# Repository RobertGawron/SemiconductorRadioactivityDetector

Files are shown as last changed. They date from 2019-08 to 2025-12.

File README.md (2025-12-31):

# Semiconductor Radioactivity Detector

## Summary

There are many ways to measure radioactivity levels. Semiconductor detectors sense interactions between ionizing radiation and a p-n junction. Since most hobbyists use Geiger-Muller-based detectors (which are lamp-based devices, not semiconductors), I think it's a cool idea to explore this semiconductor-based approach.

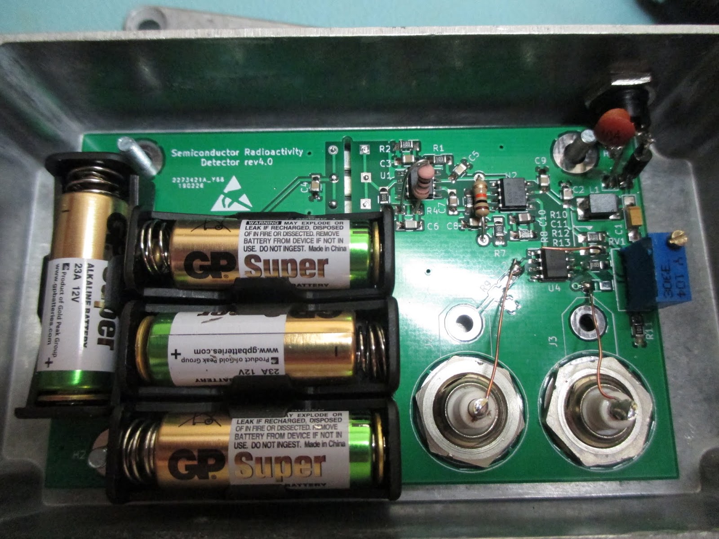
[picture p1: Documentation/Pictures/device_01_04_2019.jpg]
sensor viewed from the inside


## System Architecture

System Architecture of the Semiconductor Radioactivity Detector

## Additional sub-components used

### Hardware Data Logger

A pulse counter based on the STM32 and ESP chips that can send the measurements via WiFi for further processing, store them on an SD card, or display them to the user. This is an [open-source and open-hardware project that I created, available on GitHub.](https://github.com/RobertGawron/HardwareDataLogger)

### Auxiliary Board (Power Supply + Logic Level Converter)

An auxiliary board was developed later on to fix things that weren’t included on the original board (because it's easier to add a new board than to rework the whole device). This board isn’t really a successful one, but it does its job. It has:

**12V power supply (powered from a 15V wall adapter).** The device needs a very low-noise power supply. Originally, it was powered by a high-quality lab power supply. However, to make it more versatile, I tried using a cheap Chinese power supply and add a board with a power regulator. 

In the first revision, I chose the NCP1117 stabiliser, but it was too noisy. This caused the sensor's output to oscillate randomly, which made the device rather pointless. I made it work by adding plenty of capacitors on the input and output, though this was always a temporary solution. 

In the new version, I will be replacing it with the TPS7A2601DRVR.

**Logic level converter,** to convert logic levels from 12V (high) and 0V (low)—as output by the sensor—to 3.3V (high) and 0V (low), which is standard for STM32 and cheap Chinese logic analyzers. 

In the first version, I just used an open-collector configuration, but this made the device unable to work directly with cheap 3.3V logic analyzers, which need either 0V (low state) or 3.3V (high state).

In the new version, I added a cheap 3.3V stabiliser to provide the correct high state.

## Hardware

All hardware was done using KiCad.

The sensor assembly needs care, as this device is extremely sensitive; [more details are presented in this README.](./Hardware/SemiconductorRadioactivityDetector/README.md)

The sensor circuit is shown below.

Circuit of the Semiconductor Radioactivity Detector

The new design of the auxiliary board is shown below, integrated with the whole device. It's the small PCB on the right side of the image. The render was done using Blender.

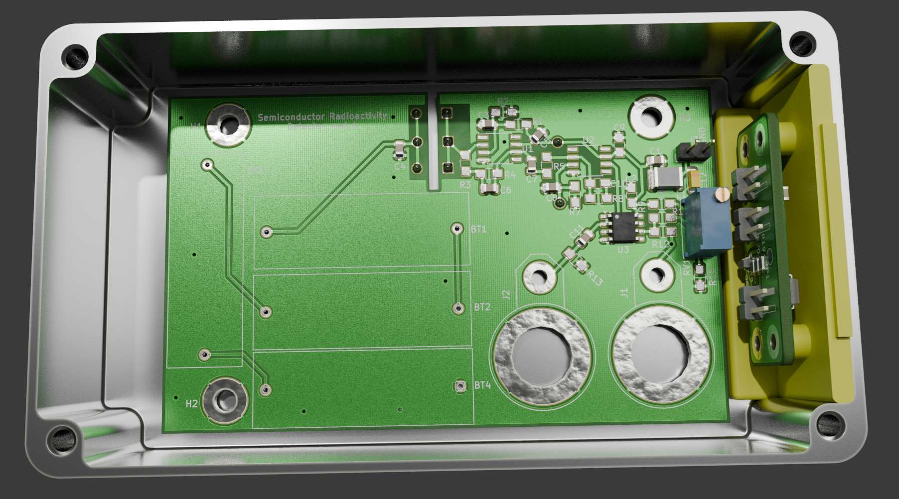
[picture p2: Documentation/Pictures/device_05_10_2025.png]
Auxiliary Board


Circuit of the Auxiliary Board is shown below.

Circuit of the Auxiliary Board

## Mechanic

Before ordering PCBs and the 3D print for the auxiliary holder, how could I be sure everything would fit? Instead of redoing things many times, I took the model of the old PCB, the new PCB that would be the addition to it, the 3D holder, and the metal enclosure (which is a popular consumer enclosure), placed them all accordingly in Blender, and checked if everything fit.

[The needed tools and the workflow are presented in this README.](./Mechanic/README.md)

## Software

[There are some Python and R scripts available](./Software/DataAcquisition/) for gathering data from the device. These were developed during the initial testing phase and may still be useful due to their simplicity.

In the future, the goal is to transition to using the [Hardware Data Logger](https://github.com/RobertGawron/HardwareDataLogger), which provides a more versatile and efficient way to collect measurements.

## Project History

 * [First Unsuccessful Attempts](https://robertgawron.blogspot.com/2016/12/semiconductor-radioactivity-detector.html)
semiconductor-radioactivity-detector.html) - the biggest issue was the lack of proper shielding. Due to the extremely high amplification levels, the device either failed to function or began oscillating uncontrollably without adequate shielding.
* [First Working Version](https://robertgawron.blogspot.com/2019/02/semiconductor-radioactivity-detector.html) - this was a simplified version of the current project. It lacked both polarization voltage and an ADC converter, but it laid the foundation for further improvements.

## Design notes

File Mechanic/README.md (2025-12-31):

# Purpose

Create a 3D-printed holder for the auxiliary board and visualize in Blender if it, the PCBs, and the chassis all fit together.

# Needed tools

* 1x https://www.tme.eu/Document/f0db5de1affb473276670eeca20421a8/hm-1550b.pdf
* 4x M2.5 nuts
* 4x Heat Set Insert Nuts M2.5 outside diameter 4mm
* 1x 3d printed model of the [PcbTray](./PcbTray/) - see more details below.

# Needed Software

* KiCad (for PCB design) + the pcb2blender extension
* OpenSCAD (for modeling the 3D-printed holder) + FreeCAD (for adding fillets and for file format conversion)
* Blender (to merge it all) + the pcb2blender extension

# Modeling Everything in Blender

It is to visualize how all the components fit together. This is only needed when changing the board's dimensions, hole placement, or the design of the PCB holder.

### Export the PCB from KiCad to Blender. 

Fortunately, there is a KiCad/Blender extension called pcb2blender that needs to be installed in both tools. The exported file needs to have the .pcb3d extension; otherwise, Blender fails to import it and the error message says nothing useful.

### Export STL models from FreeCAD to Blender

FreeCAD can export files to .STL, which Blender can then import. During the import in Blender, the scale of the .STL object needs to be set to 0.001. I don't know why.

### Export STEP models to Blender

The model of the metal enclosure for the device I found on the producer’s site, although it was in .STEP format, which Blender doesn't recognize. FreeCAD can import .STEP files and then export them to .STL, which works for Blender.

### Arrange models in Blender 

Now, when all the models are imported into Blender, it's time to arrange them in x, y, z and rotate them so they compose a real device. This could be done manually but would be very tedious; fortunately, Blender can be scripted in Python, and this way all objects can be correctly positioned. Just click the "Run" icon in Blender's scripting section. 

The script is in the project's repo too, it's just that it's not directly visible, but can be accessed via the "Scripting" tab in Blender once the Blender project is opened.

# Modeling the Auxiliary PCB Holder

It is to generate the file for 3D printing.

* The model is created in OpenSCAD.
* In FreeCAD, create a new project and click File > Open to select the OpenSCAD file.
* Add fillets to the model.
* Click File > Export and save it as an .stl file.

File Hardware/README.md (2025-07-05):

# Hardware

* [Semiconductor Radioactivity Detector](./SemiconductorRadioactivityDetector) - the main project for the sensor.
* [Power Supply + Logic Level Converter](./PowerSupply/) - auxiliary board to provide stable and low-noise power to the sensor, and to convert logic levels from 12V (high) and 0V (low) — as output by the sensor — to 3.3V (high) and 0V (low), which is standard for STM32 and cheap Chinese logic analyzers.

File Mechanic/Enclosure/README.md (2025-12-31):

# Specification

Datasheet of the Chassis:

https://www.tme.eu/Document/f0db5de1affb473276670eeca20421a8/hm-1550b.pdf

.STEP model:

https://www.hammfg.com/part/1550B?referer=electronics/small-case

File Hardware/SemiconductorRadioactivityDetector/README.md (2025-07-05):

# Extra Modifications

* The device needs to be completely shielded from sunlight and electromagnetic interference. It should be placed in a grounded metal case. Where the sensor is located, a hole should be drilled and covered with aluminum foil. This taped hole is necessary because the metal enclosure is too thick and would block too much of the radiation. The foil is needed because the signal from sunlight is much stronger, and it would overwhelm the sensor, effectively turning it into a light detector.
* As close as possible to the input power socket, I placed 1n/16V and 100n/16V capacitors in parallel. Without them, the device began oscillating randomly.
* A Schottky diode is connected in series after the extra capacitors mentioned above to reduce the risk of damaging the device when the power supply is connected incorrectly. I'm not sure if it will help enough, but I’ve already damaged one PCB this way, so now it's included.

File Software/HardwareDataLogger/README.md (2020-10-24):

# HardwareDataLogger

 

## Summary

It's a simple hardware data logger, that presents data both on LCD and via COM port so it's possible to gather data using PC and do further analysis. Currently it supports only pulse counting.

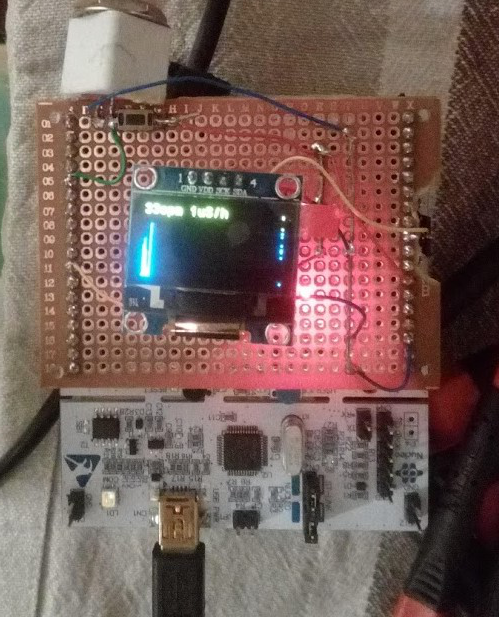
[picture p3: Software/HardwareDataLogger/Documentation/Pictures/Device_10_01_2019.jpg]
Device Picture


## Hardware

The device is based on NUCLEO-F091RC evaluation board with added custom-made shield.

TODO: hardware documentation of the shield.

## Software

Firmware were made using CubeMX, Eclipse is used for firmware development.

PC Simulation of Firmware was made using Python+Qt, it uses build .so variant of the firmware (Makefile is used for firmware variant generation).

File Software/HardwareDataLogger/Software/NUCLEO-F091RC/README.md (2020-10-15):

# Firmware for NUCLEO-F091RC board

The project has two build configurations:
* for generating binary, this is used for flashing, use Eclipse project
* for generating shared library, this is used for PC simulation, use Makefile

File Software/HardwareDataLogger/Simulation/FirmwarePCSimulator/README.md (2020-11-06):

# PC Simulator for firmware

This project consists of two parts:

- firmware that is built to sharable object (.so)
- python script that loads this sharable object, and acts as a mockup of hardware

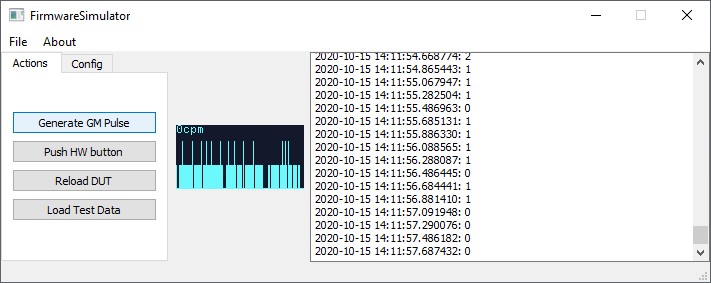
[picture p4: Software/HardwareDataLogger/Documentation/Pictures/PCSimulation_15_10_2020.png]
Simulator Picture


Note that in order to load .so object into an application, both of them needs to be 32bits, or 64bits. In case of errors during loading .so object, check your version on Python and gcc (both should be either 32bits or 64bits).

## Requirements
- Install PyQt5

```pip install PyQt5```
- Install gcc an makefile

## Usage
- Build firmware, in Software/NUCLEO-F091RC directory execute:

```make```

- Start the simulation, in Simulation/FirmwarePCSimulator execute:

```python main.py```

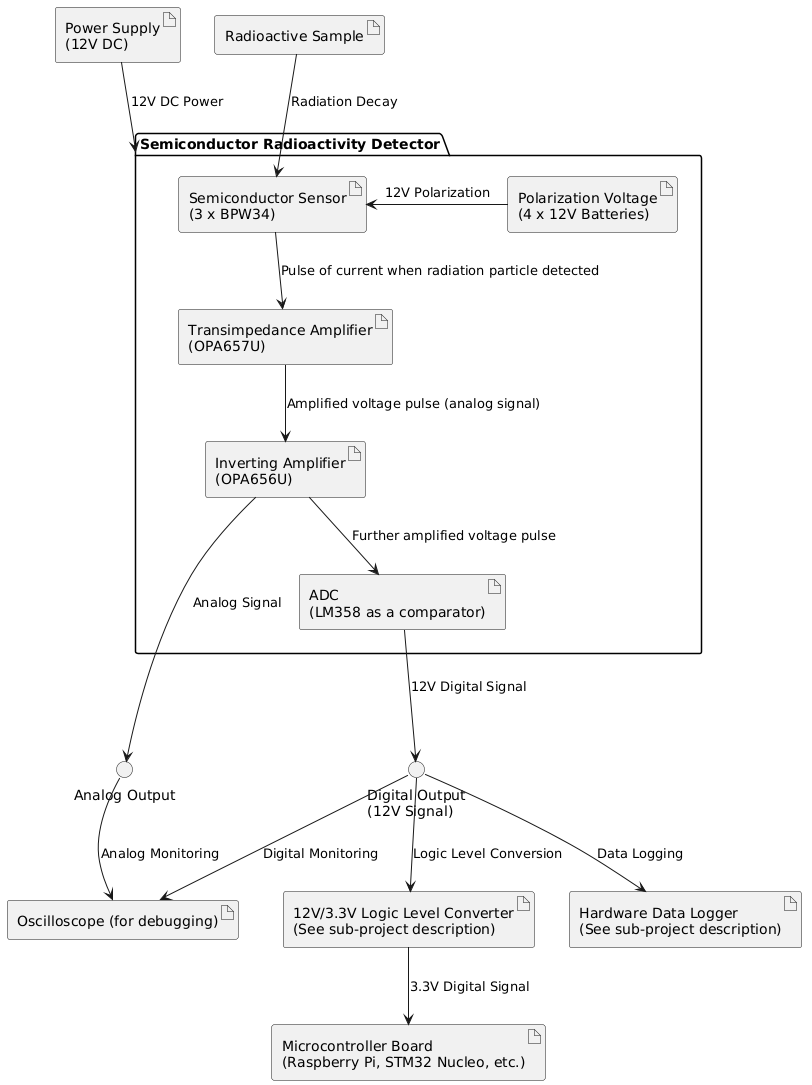
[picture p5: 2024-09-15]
Documentation/Diagrams/ArchitectureOverview-1.png

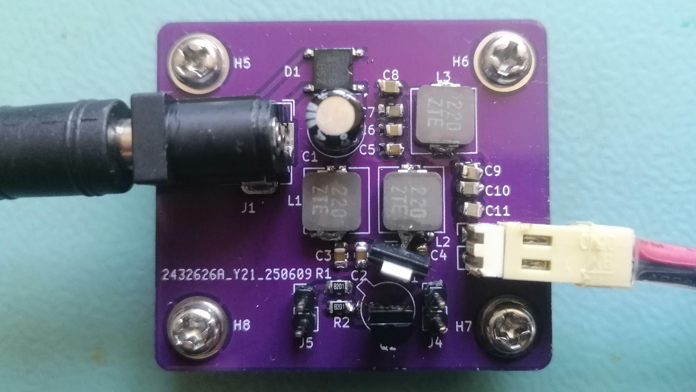
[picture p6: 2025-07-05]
Documentation/Pictures/auxiliary_board_05_07_2025.jpg

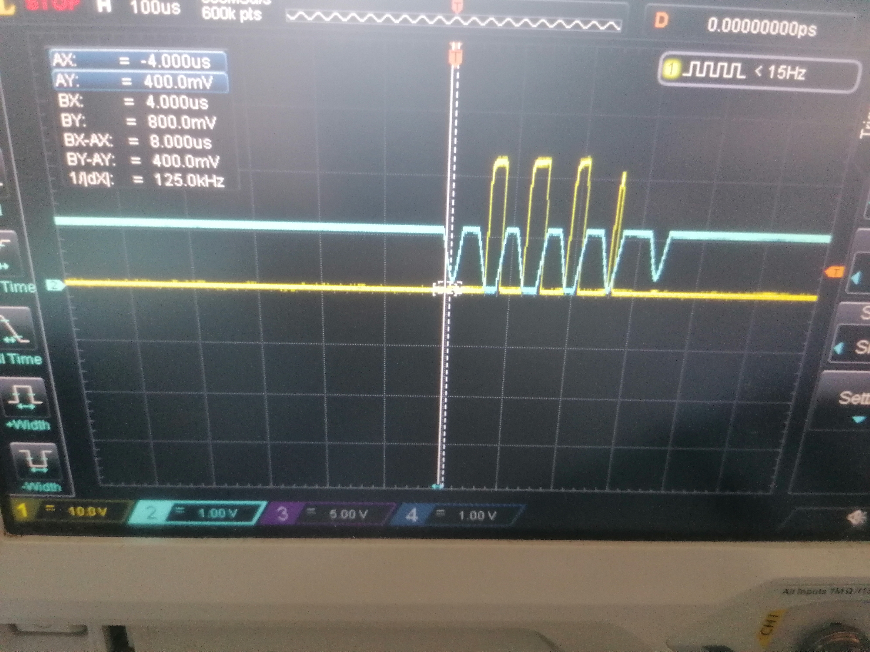
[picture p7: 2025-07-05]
Documentation/Pictures/distortion_05_07_2025.jpg

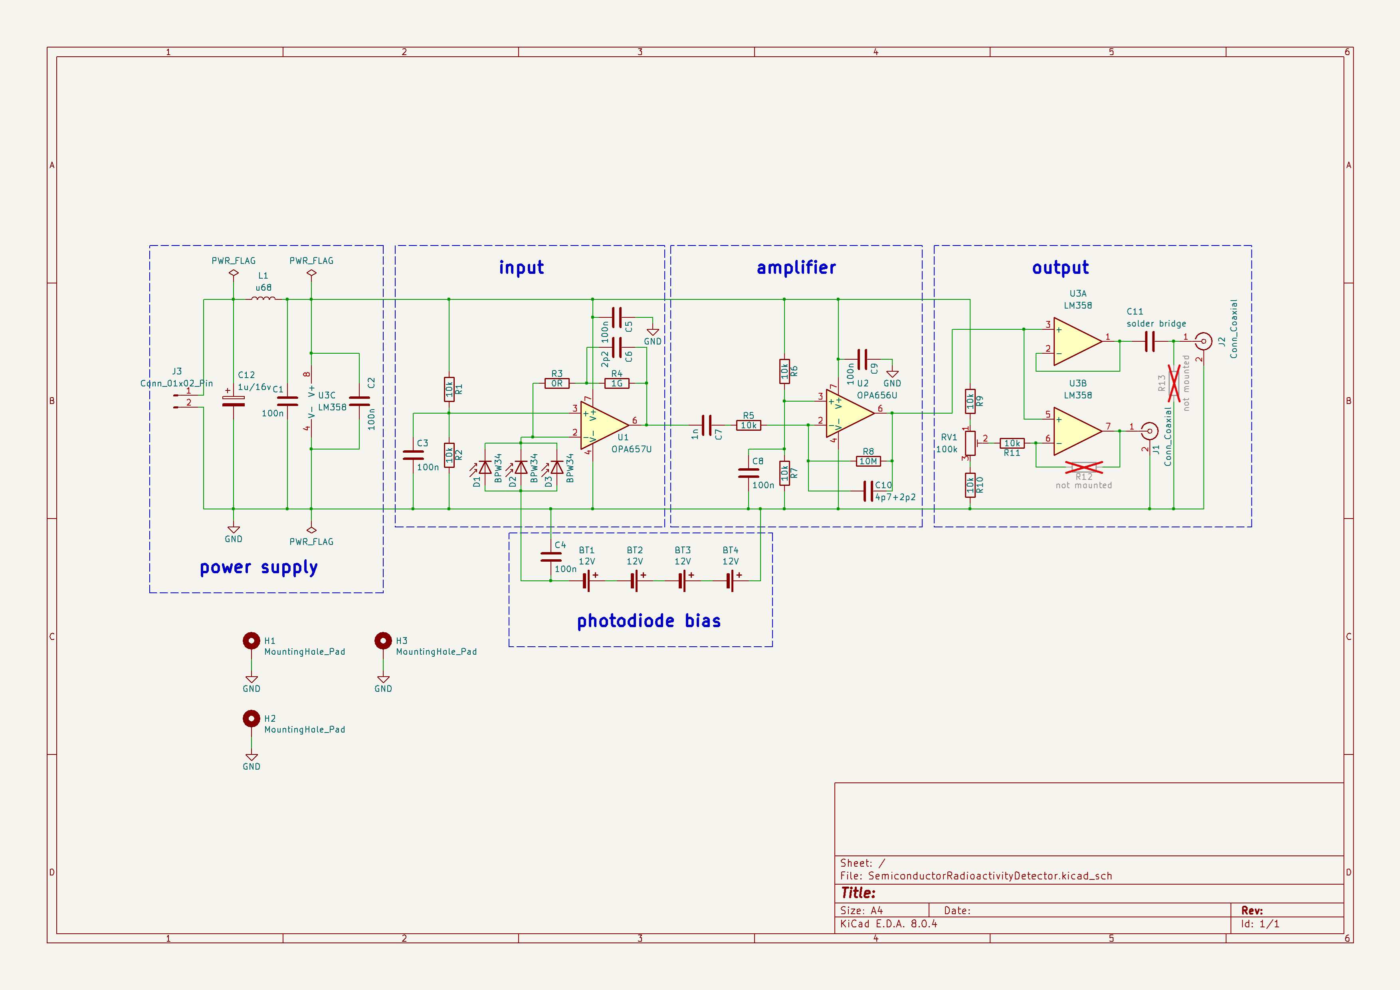
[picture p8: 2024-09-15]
Documentation/Diagrams/Circuit.png

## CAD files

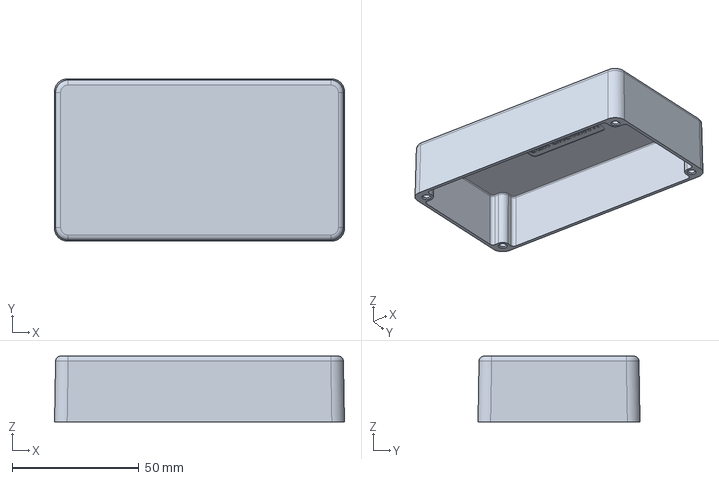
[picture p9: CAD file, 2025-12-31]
Mechanic/Enclosure/Enclosure.FCStd
114.5 x 64.0 x 26.0 mm

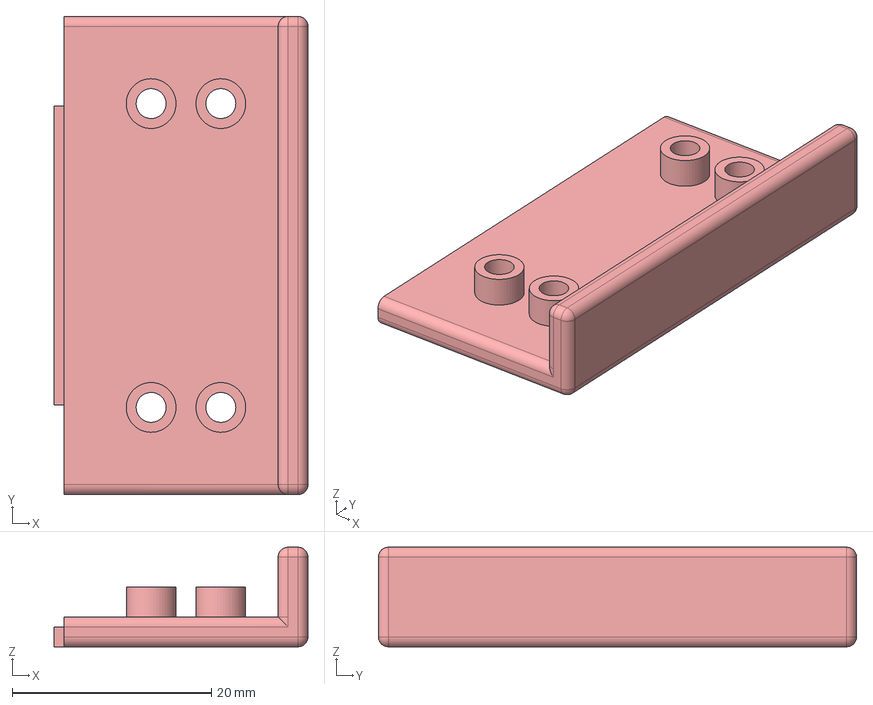
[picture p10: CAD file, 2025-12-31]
Mechanic/PcbTray/Holder.FCStd
25.5 x 48.0 x 10.0 mm
circle
circle001
circle002
circle003
circle004
circle005
circle006
circle007
circle008
circle009
circle010
circle011

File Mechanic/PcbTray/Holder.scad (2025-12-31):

$fn = 50;

// taken from chassis datasheet
wall_thickness = 1.5;
chassis_inner_thickness = 26 - wall_thickness;

// the printed element is a sum of simple boxes
// this is the default thickness of them
mainboard_thickness = 3;

// The dent holds the holder in Z position
// it is placed between bottom and top chassis
// the top chassis has an inner aureola that
// doesn't touch the bottom chassis
// this space is where the dent goes
module upper_dent_3d() {
    // taken from chassis 3d model
    x = chassis_inner_thickness + 0.5;
    y = 30;
    z = 4.5 - 2.5;

    translate([-wall_thickness/2, 0, 0])
    linear_extrude(height = z)
    square([x, y], center = true);
}

// bottom part to make sure PCB stays in place
module bottom_bar_3d() { 
    // taken from chassis datasheet 
    x = mainboard_thickness;
    y = 48;
    z = 10;
    
    translate([chassis_inner_thickness/2 - x/2, 0, 0])
    linear_extrude(height = z)
    square([x, y], center = true);
}

// helper to create a single nut insertion
module insert_nut_wall_2d(x, y, inner_d, outer_d) {
    translate([x, y, 0]) {
        difference() {
            circle(d = outer_d);
            circle(d = inner_d);
        }
    }
}

// four nuts to mount the PCB
module pcb_nuts_holders_3d(x, y, d_in, thickness, z) {
    d_out = d_in + thickness;
    
    linear_extrude(height = z) {
        for (sx = [-1, 1]) {
            for (sy = [-1, 1]) {
                insert_nut_wall_2d(sx*x, sy*y, d_in, d_out);
            }
        }
    }
}

module nuts_cutout_3d(x, y, d_in, z) {
    linear_extrude(height = z) {
        for (sx = [-1, 1]) {
            for (sy = [-1, 1]) {
                translate([sx*x, sy*y, 0]) 
                    circle(d = d_in);
            }
        }
    }
}

// part where all other parts connect to
module mainboard_3d() {
    // taken from chassis datasheet
    linear_extrude(height = mainboard_thickness)
    square([chassis_inner_thickness, 48], center = true);
}

// instantiate all modules
// union not needed but made for FreeCAD export issues
module main_pcb_holder_3d() {
    // X-Y positions taken from kicad model
    // for the auxiliary board
    x = 3.5;
    y = 30.5 / 2;
    
    // Heat Set Insert Nuts diameter from specs
    // 4mm outside, make tight so it stays
    d_in_holder = 4 - 1;
    thickness = 2;
    z_holder = mainboard_thickness + 3;
    z_cutout = mainboard_thickness;
    
    difference() {
        union() {
            mainboard_3d();
            upper_dent_3d();
            bottom_bar_3d();
            pcb_nuts_holders_3d(x, y, d_in_holder, thickness, z_holder);
        }
        nuts_cutout_3d(x, y, d_in_holder, z_cutout);
    }
}

main_pcb_holder_3d();

// DONT FORGET TO ADD FILLETS in FREECAD
// they are important because printed part will
// fit to chassis that already has fillets
// they can't be omitted, parts won't fit!

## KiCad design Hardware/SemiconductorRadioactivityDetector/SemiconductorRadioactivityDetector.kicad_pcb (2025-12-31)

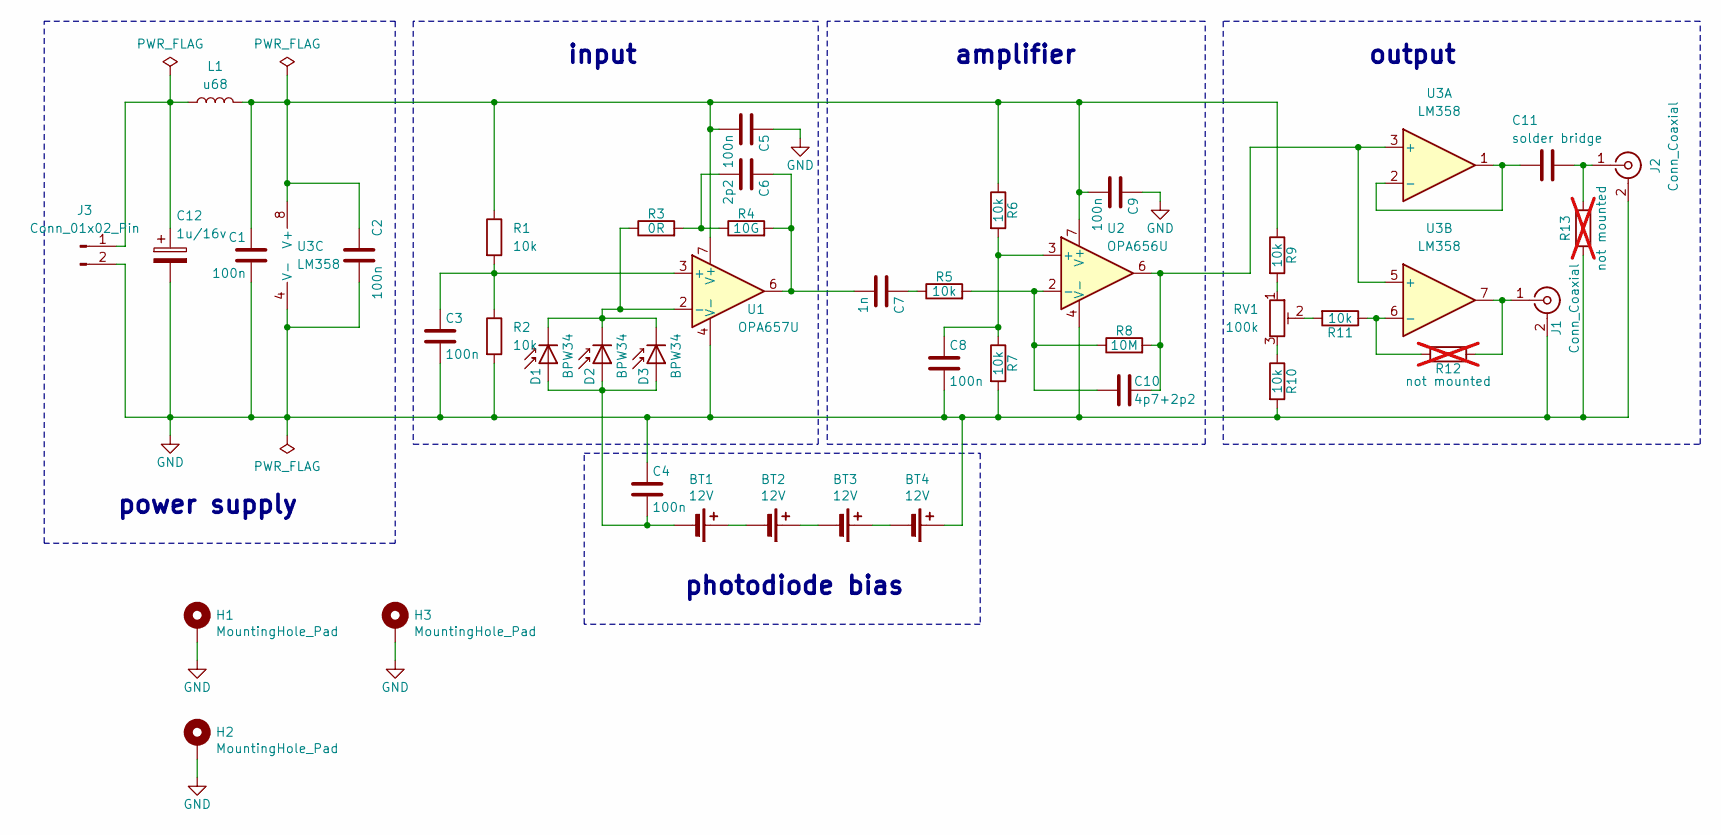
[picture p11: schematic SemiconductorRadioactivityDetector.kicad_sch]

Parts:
BT1, BT2, BT3, BT4: 12V; A23Single
C1, C3, C4, C5, C8: 100n; C_0805_2012Metric
C2, C9: 100n; C_0805_HandSoldering
C6: 2p2; C_0805_2012Metric
C7: 1n; C_0805_2012Metric
C10: 4p7+2p2; C_0805_HandSoldering
C11: solder bridge; C_0805_2012Metric
C12: 1u/16v; CP_EIA-3216-18_Kemet-A
D1, D2, D3: BPW34; D_DO-35_SOD27_P5.08mm_Vertical_KathodeUp
H1, H2, H3: MountingHole_Pad; MountingHole_3.5mm_Pad
J1, J2: Conn_Coaxial; BNC_PanelMountable_Vertical
J3: Conn_01x02_Pin; PinHeader_1x02_P2.54mm_Vertical
L1: u68; L_1812_4532Metric
R1, R2, R5, R7, R9, R10, R11: 10k; R_0805_HandSoldering
R3: 0R; R_0805_HandSoldering
R4: 10G; R_0805_HandSoldering
R6: 10k; R_Axial_DIN0207_L6.3mm_D2.5mm_P10.16mm_Horizontal
R8: 10M; R_0805_HandSoldering
R12, R13: not mounted; R_0805_HandSoldering; not fitted
RV1: 100k; Potentiometer_Bourns_3296W_Vertical
U1: OPA657U; SOIC-8_3.9x4.9mm_Pitch1.27mm
U2: OPA656U; SOIC-8_3.9x4.9mm_Pitch1.27mm
U3: LM358; SOIC-8_3.9x4.9mm_P1.27mm

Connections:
GND: BT4.1 (+), C1.2, C2.2, C3.2, C4.1, C5.1, C8.2, C9.1, C12.2, H1.1, H2.1, H3.1, J1.2 (Ext), J2.2 (Ext), J3.2, R2.2, R7.2, R10.2, R13.2, U1.4 (V-), U2.4 (V-), U3.4 (V-)
unnamed: BT1.1 (+), BT2.2 (-)
unnamed: BT1.2 (-), C4.2, D1.2 (A), D2.2 (A), D3.2 (A)
unnamed: BT2.1 (+), BT3.2 (-)
unnamed: BT3.1 (+), BT4.2 (-)
unnamed: C6.1, C7.2, R4.2, U1.6
unnamed: C6.2, R3.2, R4.1
unnamed: C7.1, R5.1
unnamed: D1.1 (K), D2.1 (K), D3.1 (K), R3.1, U1.2 (-)
unnamed: J1.1 (In), R12.1, U3.7
unnamed: C11.1, J2.1 (In), R13.1
unnamed: C12.1, J3.1, L1.1
unnamed: R9.2, RV1.1
unnamed: R10.1, RV1.3
unnamed: R11.2, RV1.2
unnamed: C3.1, R1.2, R2.1, U1.3 (+)
unnamed: C1.1, C2.1, C5.2, C9.2, L1.2, R1.1, R6.1, R9.1, U1.7 (V+), U2.7 (V+), U3.8 (V+)
unnamed: C8.1, R6.2, R7.1, U2.3 (+)
unnamed: C10.2, R5.2, R8.1, U2.2 (-)
unnamed: C10.1, R8.2, U2.6, U3.3 (+), U3.5 (+)
unnamed: C11.2, U3.1, U3.2 (-)
unnamed: R11.1, R12.2, U3.6 (-)

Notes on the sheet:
input
amplifier
power supply
output
photodiode bias

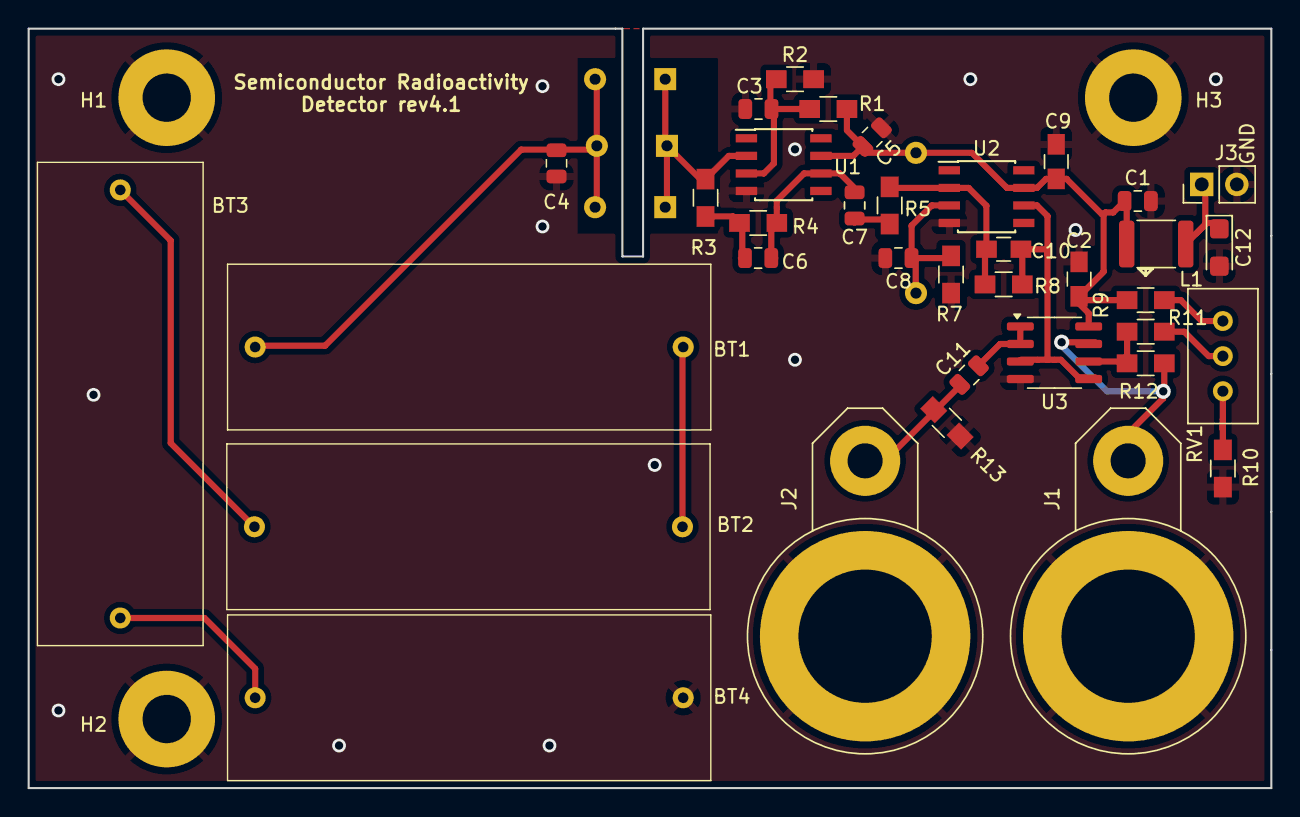
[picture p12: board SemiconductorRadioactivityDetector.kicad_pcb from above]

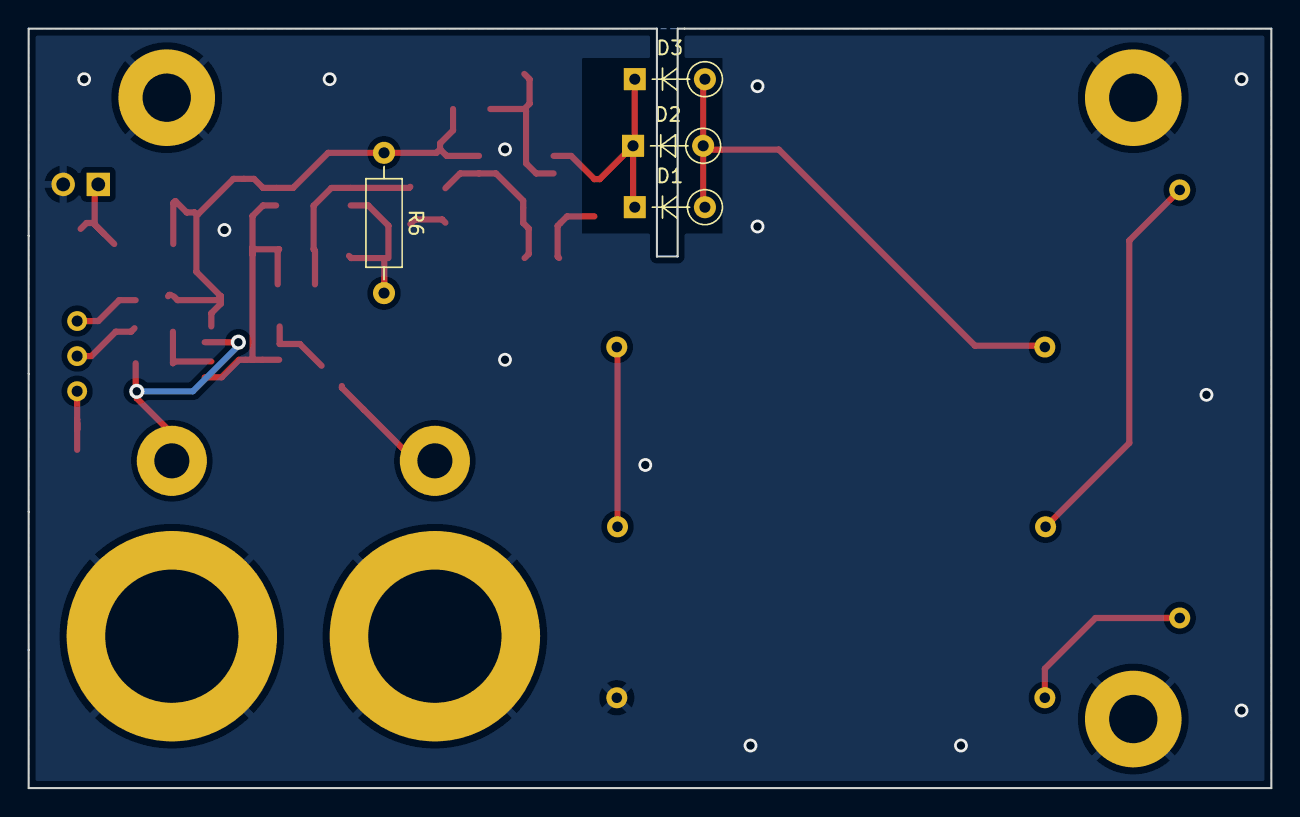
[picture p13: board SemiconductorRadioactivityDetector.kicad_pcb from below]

Board: 2 copper layers, 90.0 x 55.0 mm, 43 parts (4 on the bottom side), 22 nets.

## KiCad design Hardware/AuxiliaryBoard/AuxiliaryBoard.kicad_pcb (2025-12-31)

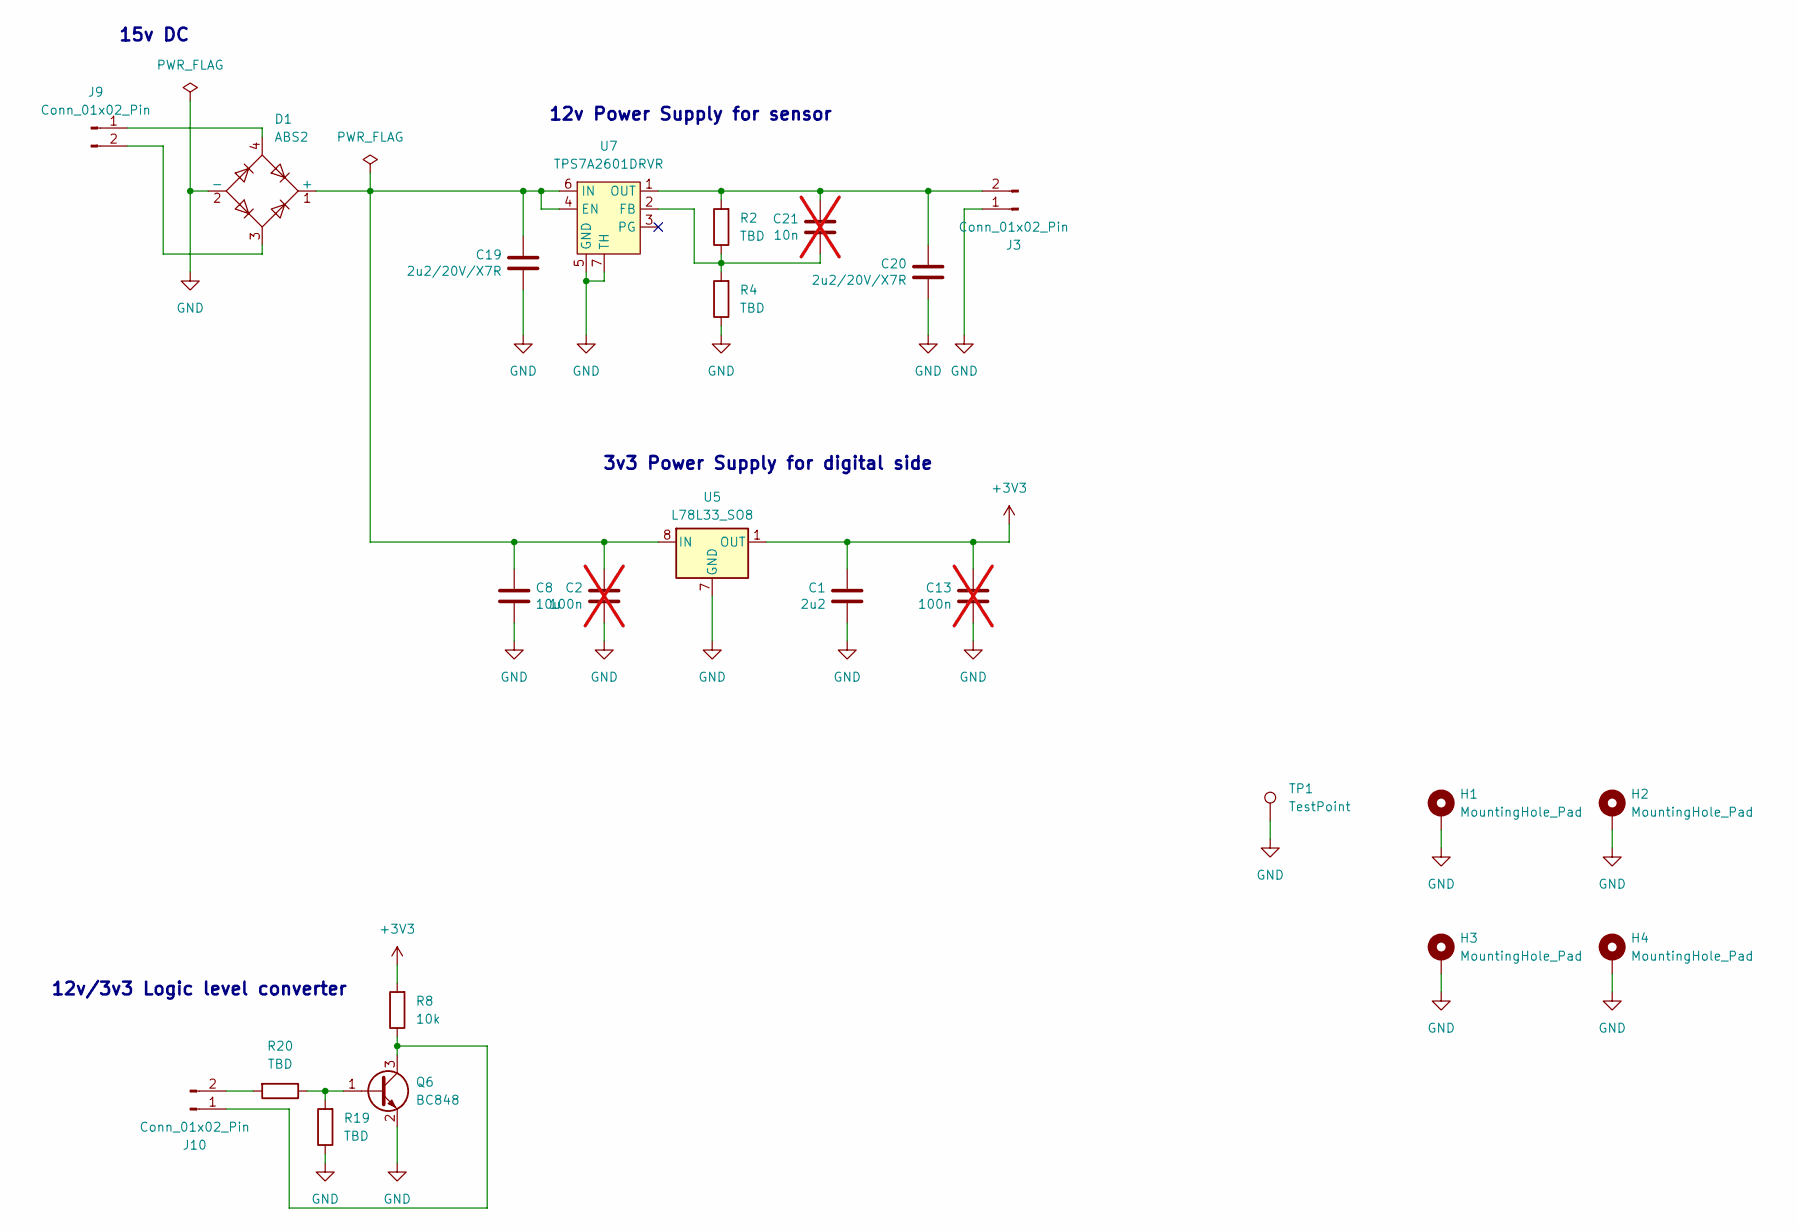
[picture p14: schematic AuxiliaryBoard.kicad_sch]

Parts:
C1: 2u2; C_0805_2012Metric
C2, C13: 100n; C_0805_2012Metric; not fitted
C8: 10u; C_0805_2012Metric
C19, C20: 2u2/20V/X7R; C_0805_2012Metric
C21: 10n; C_0805_2012Metric; not fitted
D1: ABS2; Diode_Bridge_Diotec_ABS
H1, H2, H3, H4: MountingHole_Pad; MountingHole_2.5mm_Pad
J3, J9, J10: Conn_01x02_Pin; PinHeader_1x02_P2.54mm_Horizontal
Q6: BC848; SOT-23
R2, R4: TBD; R_Axial_DIN0204_L3.6mm_D1.6mm_P5.08mm_Horizontal
R8: 10k; R_0805_2012Metric
R19, R20: TBD; R_0805_2012Metric
TP1: TestPoint; TestPoint_Pad_D2.0mm
U5: L78L33_SO8; SOIC-8_3.9x4.9mm_P1.27mm
U7: TPS7A2601DRVR; WSON-6-1EP_2x2mm_P0.65mm_EP1x1.6mm

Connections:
+3V3: C1.1, C13.1, R8.2, U5.1 (OUT)
GND: C1.2, C2.2, C8.2, C13.2, C19.2, C20.2, D1.2 (-), H1.1, H2.1, H3.1, H4.1, J3.1, Q6.2 (E), R4.1, R19.1, TP1.1, U5.2 (GND), U5.3 (GND), U5.6 (GND), U5.7 (GND), U7.5 (GND), U7.7 (TH)
unnamed: C2.1, C8.1, C19.1, D1.1 (+), U5.8 (IN), U7.4 (EN), U7.6 (IN)
unnamed: C20.1, C21.1, J3.2, R2.2, U7.1 (OUT)
unnamed: D1.4, J9.1
unnamed: D1.3, J9.2
unnamed: J10.1, Q6.3 (C), R8.1
unnamed: J10.2, R20.2
unnamed: Q6.1 (B), R19.2, R20.1
unnamed: C21.2, R2.1, R4.2, U7.2 (FB)

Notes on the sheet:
12v/3v3 Logic level converter
3v3 Power Supply for digital side
12v Power Supply for sensor
15v DC

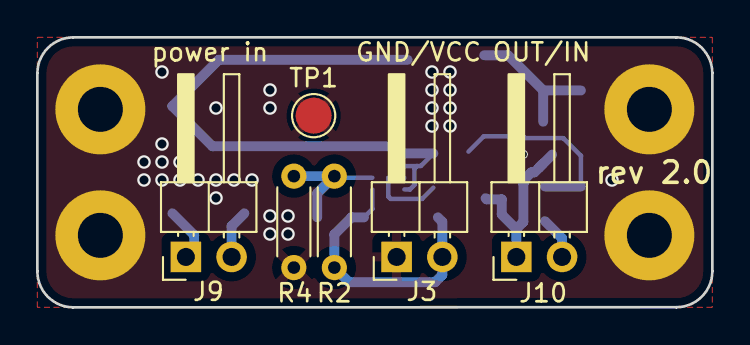
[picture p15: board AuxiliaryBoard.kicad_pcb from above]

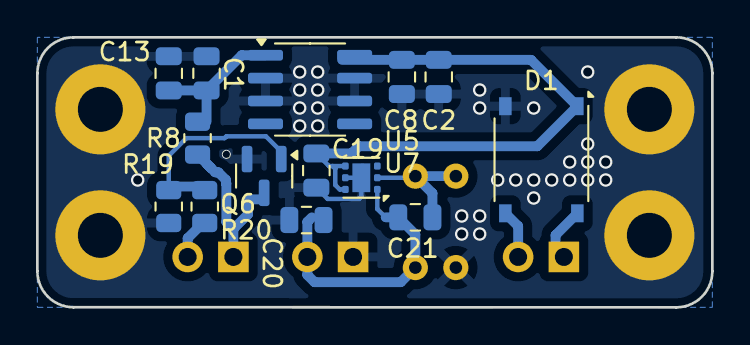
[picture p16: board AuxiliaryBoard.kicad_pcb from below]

Board: 2 copper layers, 37.5 x 15.0 mm, 24 parts (14 on the bottom side), 10 nets.

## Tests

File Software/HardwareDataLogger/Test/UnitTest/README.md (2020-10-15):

# Unit Tests

[UTest](https://github.com/sheredom/utest.h) is used as a test framework due to its simplicity.

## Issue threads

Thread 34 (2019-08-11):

Fix README.md

RobertGawron, 2019-08-11:
"12V -> 5V logic converter" - it's 3V3 not 5V

Closed 2019-08-11.

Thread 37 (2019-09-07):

In README.md "12V -> 3V3 logic converter" links is leading to wrong Wiki page.

RobertGawron, 2019-09-07:

Closed 2019-09-08.

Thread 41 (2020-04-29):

Capacitor C1 burns when I switched the Power On

AbidHussain70, 2020-04-29:

RobertGawron, 2020-05-01:
@AbidHussain70: could you please say what the problem was? You closed the issue so I think you resolved it by yourself, the info about issue would be good for me and maybe other people who try to build the same device.

AbidHussain70, 2020-05-08:
I made a new PCB. When I receive the PCB I will solder the components and will update.

AbidHussain70, 2020-05-11:
Hi,
I made a new PCB and I solder the components, I am getting almost 2.4 V in the photo-diode, and almost 3.6 V across C4 capacitor, when I switched On the power. But after sometime the voltage across C4 jumps to 5 V and the voltage the photo-diode  terminal goes under 1 V. These are measurement without attaching photo-diodes to the terminal.
What should be the voltage across the photo-diode terminal? And does the voltage of the C4 varies with the load? (I mean if I attached the photo-diodes).

AbidHussain70, 2020-05-11:
I attached the photo-diodes and now the voltage across photo-diode is 2.5 V.

RobertGawron, 2020-05-11:
@AbidHussain70:
>What should be the voltage across the photo-diode terminal?
By "terminal" you mean + input of operation amplifier (I mean pin 3 of U1)? If yes, then + and - pins have the same voltage measured to ground and - pin has voltage created by voltage divider R1+R2 = half of the power supply voltage.

>And does the voltage of the C4 varies with the load? (I mean if I attached the photo-diodes).
The voltage will be always the same - it should be -4x12V (measured on pins of C4)

1. What is the voltage on pin 3 of the U1?
2. What's the voltage on pin 2 of U1?

AbidHussain70, 2020-05-13:
By terminal I mean the input voltage for photo-diodes.

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

I made a small socket for Photo-diodes, and placed a connector on main board. The socket will be installed on the `connector.

`
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

RobertGawron, 2020-05-21:
@AbidHussain70: I see you created your own PCB and modified a a bit schematic.

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

What is the purpose of D1-D4 and are they connected in correct polarization? Can you check if voltage on terminal (I marked is as 1) is roughly -4x12V?

Closed 2024-09-13.

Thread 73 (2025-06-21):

[PowerSupply] fix IC1 footprint

RobertGawron, 2025-06-21:

RobertGawron, 2025-07-05:
Will not be fixed because the board will be redesigned.

Closed 2025-07-05.

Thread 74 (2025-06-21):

[PowerSupply] add 10uF cap on IC1 output

RobertGawron, 2025-06-21:

RobertGawron, 2025-07-05:
Will not be fixed because the board will be redesigned.

Closed 2025-07-05.

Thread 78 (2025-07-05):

[AuxiliaryBoard] Rename Kicad project from PowerSupply to AuxiliaryBoard

RobertGawron, 2025-07-05:

RobertGawron, 2025-10-05:
Done in [#8044d](https://github.com/RobertGawron/SemiconductorRadioactivityDetector/commit/8044d96009f41e0b8b1c81da68d0a1d23be74c48)

Closed 2025-10-05.

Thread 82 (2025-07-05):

[AuxiliaryBoard] Choose dimension of the mounting holes, also they shouldn't be plated

RobertGawron, 2025-07-05:

RobertGawron, 2025-10-05:
Done in [#8044d](https://github.com/RobertGawron/SemiconductorRadioactivityDetector/commit/8044d96009f41e0b8b1c81da68d0a1d23be74c48)

Closed 2025-10-05.

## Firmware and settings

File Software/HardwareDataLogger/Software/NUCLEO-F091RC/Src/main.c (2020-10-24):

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

/* Includes ------------------------------------------------------------------*/
#include "main.h"

/* USER CODE BEGIN Includes */

#include "gm_display_updater.h"
#include "gm_measurement_calculator.h"
#include "gm_logger.h"
#include "gm_keyboard.h"

/* USER CODE END Includes */

I2C_HandleTypeDef hi2c1;

TIM_HandleTypeDef htim2;

UART_HandleTypeDef huart2;

void SystemClock_Config(void);
static void MX_GPIO_Init(void);
static void MX_USART2_UART_Init(void);
static void MX_TIM2_Init(void);
static void MX_I2C1_Init(void);
/**
  * @brief  The application entry point.
  * @retval int
  */
int main(void)
{
  /* MCU Configuration--------------------------------------------------------*/

  /* Reset of all peripherals, Initializes the Flash interface and the Systick. */
  HAL_Init();

  /* Configure the system clock */
  SystemClock_Config();

  /* Initialize all configured peripherals */
  MX_GPIO_Init();
  MX_USART2_UART_Init();
  MX_TIM2_Init();
  MX_I2C1_Init();
  /* USER CODE BEGIN 2 */

  // TODO maybe add some module like ApplicationBuilder?
  GMDisplayUpdater_Init();
  GMMeasurementCalculator_Init();
  GMLogger_Init();
  GMKeyboard_Init();

  HAL_TIM_Base_Start_IT(&htim2);      //start timer2 in interrupt mode.

  /* USER CODE END 2 */

  /* Infinite loop */
  /* USER CODE BEGIN WHILE */
  while (1)
  {
    /* USER CODE END WHILE */

    /* USER CODE BEGIN 3 */
  }
  /* USER CODE END 3 */
}

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


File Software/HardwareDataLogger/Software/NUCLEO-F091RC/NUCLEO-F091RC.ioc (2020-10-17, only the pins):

Mcu.UserName=STM32F091RCTx
PA10.Signal=I2C1_SDA
PA13.GPIO_Label=TMS
PA13.Signal=SYS_SWDIO
PA14.GPIO_Label=TCK
PA14.Signal=SYS_SWCLK
PA2.GPIO_Label=USART_TX
PA2.Signal=USART2_TX
PA3.GPIO_Label=USART_RX
PA3.Signal=USART2_RX
PA5.GPIO_Label=LD2 [Green Led]
PA5.Signal=GPIO_Output
PA9.Signal=I2C1_SCL
PB5.GPIO_Label=GMPulseInput
PB5.Signal=GPXTI5
PC13.GPIO_Label=Button
PC13.Signal=GPXTI13
PC14OSC32_IN.Signal=RCC_OSC32_IN
PC15OSC32_OUT.Signal=RCC_OSC32_OUT
PF0-OSC_IN.Signal=RCC_OSC_IN
PF1-OSC_OUT.Signal=RCC_OSC_OUT

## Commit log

2017-01-14 Initial commit.
    [main.brd, main.sch]
2018-05-27 Removed old obsolete version.
    [main.brd, main.sch]
2018-05-27 New HW version.
    [radioactivity-detector.kicad_pcb, radioactivity-detector.sch]
2018-09-18 pcb fixes before sending to factory
    [radioactivity-detector.kicad_pcb]
2018-09-19 final touch before ordering pcb
    [radioactivity-detector.kicad_pcb, radioactivity-detector.sch]
2019-02-16 initial versionwq
    [radioactivity-detector.kicad_pcb, radioactivity-detector.sch]
2019-02-24 fixed missing libraries
    [radioactivity-detector.sch]
2019-02-24 last touch before sending to pcb factory
    [radioactivity-detector.kicad_pcb, radioactivity-detector.sch]
2019-02-24 added clearance
    [radioactivity-detector.kicad_pcb]
2019-05-03 fixes after hw assembly and tests
    [radioactivity-detector.sch]
2019-08-11 fix #23
    [radioactivity-detector.kicad_pcb, radioactivity-detector.sch]
2019-09-08 sensor moved to its own subdirectory
    [radioactivity-detector.kicad_pcb, radioactivity-detector.sch]
2019-09-08 added logic converter project
    [LogicConverter.kicad_pcb, LogicConverter.sch]
2020-06-01 add basic simulator of digital filters
2020-10-15 Squashed 'Software/HardwareDataLogger/' content from commit 37d90c3
    git-subtree-dir: Software/HardwareDataLogger
    git-subtree-split: 37d90c36ef6dff2428dff3a75682a6a990aea3fe
    [NUCLEO-F091RC Debug.cfg]
2020-10-17 remove old subrepo version
    [NUCLEO-F091RC Debug.cfg]
2020-10-17 Squashed 'Software/HardwareDataLogger/' content from commit 36e64a0
    git-subtree-split: 36e64a0b74689bc3145da8180f2f13aac98a8adf
    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
    [NUCLEO-F091RC Debug.cfg]
2020-10-24 Squashed 'Software/HardwareDataLogger/' changes from 36e64a0..dc3c36e
    dc3c36e Merge pull request #21 from RobertGawron/develop
    a8342c6 Merge pull request #20 from RobertGawron/feature/add_contionous_integration
    304d8cd fix c linter issues
    4a7e1a6 Merge pull request #19 from RobertGawron/develop
    1880f22 Merge pull request #18 from RobertGawron/feature/add_contionous_integration
    7c2c33d exclude external libs from repo programming language statistics
    8b80624 Merge pull request #17 from RobertGawron/develop
    e224b3c Merge pull request #16 from RobertGawron/feature/add_contionous_integration
    b6c5e9e fixed formatting
    d7cbf0f add static code analysis build for ci (c files)
    a741c74 add static code an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
    [main.c]
2024-09-15 transition to kicad8 and docs cleanup
    [LogicConverter.kicad_pcb, LogicConverter.sch, LogicLevelConverter.kicad_pcb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]
2025-07-05 auxiliary board rev1.0
    [LogicLevelConverter.kicad_pcb, LogicLevelConverter.kicad_sch, PowerSupply.kicad_pcb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]
2025-12-31 auxiliary board rev2 + its 3d printed holder
    [AuxiliaryBoard.kicad_pcb, AuxiliaryBoard.kicad_sch, Enclosure.FCStd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]

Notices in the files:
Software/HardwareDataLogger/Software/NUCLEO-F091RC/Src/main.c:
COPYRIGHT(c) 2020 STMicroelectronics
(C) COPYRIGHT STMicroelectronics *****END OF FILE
